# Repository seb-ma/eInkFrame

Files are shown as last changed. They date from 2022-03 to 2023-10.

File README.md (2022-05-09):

# Weather station e-ink frame

This is a project (hardware and software parts) designed to have a full Weather station (and many more features) displayed on a e-ink screen put in a photo frame with tactile buttons.

It is done with a Raspberry Pi, a 7.8" e-ink screen, a capacitive touch sensor, a temperature/humidity/pressure/gas sensor and needs a internet connection.

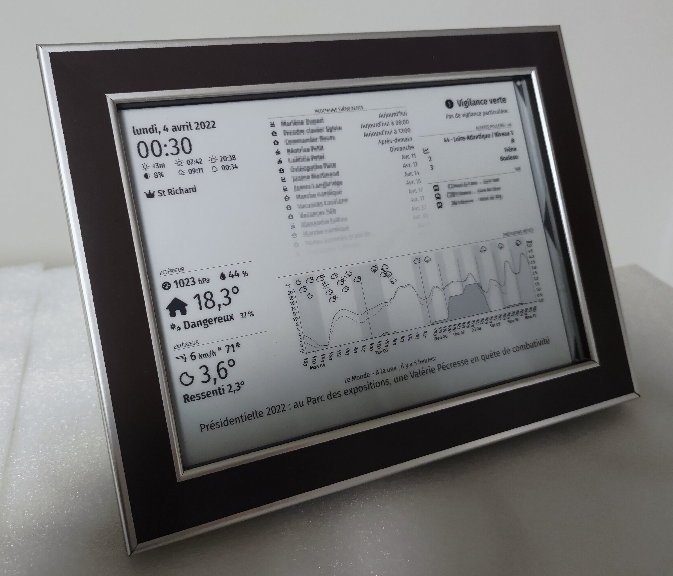
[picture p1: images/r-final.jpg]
final


## Status

This project is fully functional.

Some improvements can be done (see [MagicMirror² Installation](software.md#Disclaimer)) and more features may be added in the future (see below).

## Hardware

Complete guide is in [hardware part](hardware.md).

It includes:
- Information on schematic
- Bill Of Material

## Software

Complete guide is in [software part](software.md).

It includes:
- Installation and configuration of OS on Raspberry
- Installation and configuration of [MagicMirror²](https://magicmirror.builders/) and all the modules

## Features

At this stage, all the ticked features are available (the other features may never be done).
It can also be customized by adding new modules (see [MagicMirror² Installation](software.md#MagicMirror²)).

### Basic

- [X] Current day and time
- [X] sunrise/sunset
- [X] moonrise/moonset
- [X] Gain/loss of sun minutes since yesterday
- [X] Moon phase
- [X] Saint of the day

### Weather/outdoor

- [X] Indoor sensors:
  - [X] temperature
  - [X] humidity
  - [X] pressure
  - [X] air quality
- [X] Current weather with:
  - [X] temperature
  - [X] feel-like temperature
  - [X] humidity
  - [X] pressure
  - [X] wind
  - [X] UV index
  - [X] rain probability
  - [X] air quality
- [X] Graph of weather forecast for next days with:
  - [X] temperature
  - [X] feel-like temperature
  - [X] min/max temperature
  - [X] rain and snow
  - [X] weather icon
  - [X] humidity
  - [X] pressure
  - [X] wind
  - [X] UV index
  - [X] rain probability
  - [X] air quality
  - [ ] same curves for previous days
- [X] Alerts on the risk of rain, wind, ice...
- [X] Alerts on current active allergens
- [ ] Maps of winds, rain, lightning
- [ ] Historic graph of indoor sensor measures

### Calendar and tasks

- [X] Upcoming events in family calendar
- [X] Upcoming birthdays
- [X] Tasks (from Trello)

### Travels

- [X] Next upcoming used bus lines
  - [X] with alerts on this lines
- [X] Travel time to work
- [ ] Map of traffic
- [ ] Traffic for the next event in calendar

### Entertainment

- [X] Headlines of news
- [X] Current Spotify music (watch multiple accounts)
  - [X] with buttons for Spotify control (volume, next/previous, start/stop)
- [ ] Game of life

### Display

- [X] Different pages that can be accessed with buttons

### Advanced features (not yet planned)

- [ ] [Home Assistant](https://www.home-assistant.io/) interaction
- [ ] Communication with home sensors (indoor and outdoor)

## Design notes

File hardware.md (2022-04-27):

# Hardware part

This project was done with KiCad. Schematic and PCB are provided in this format.

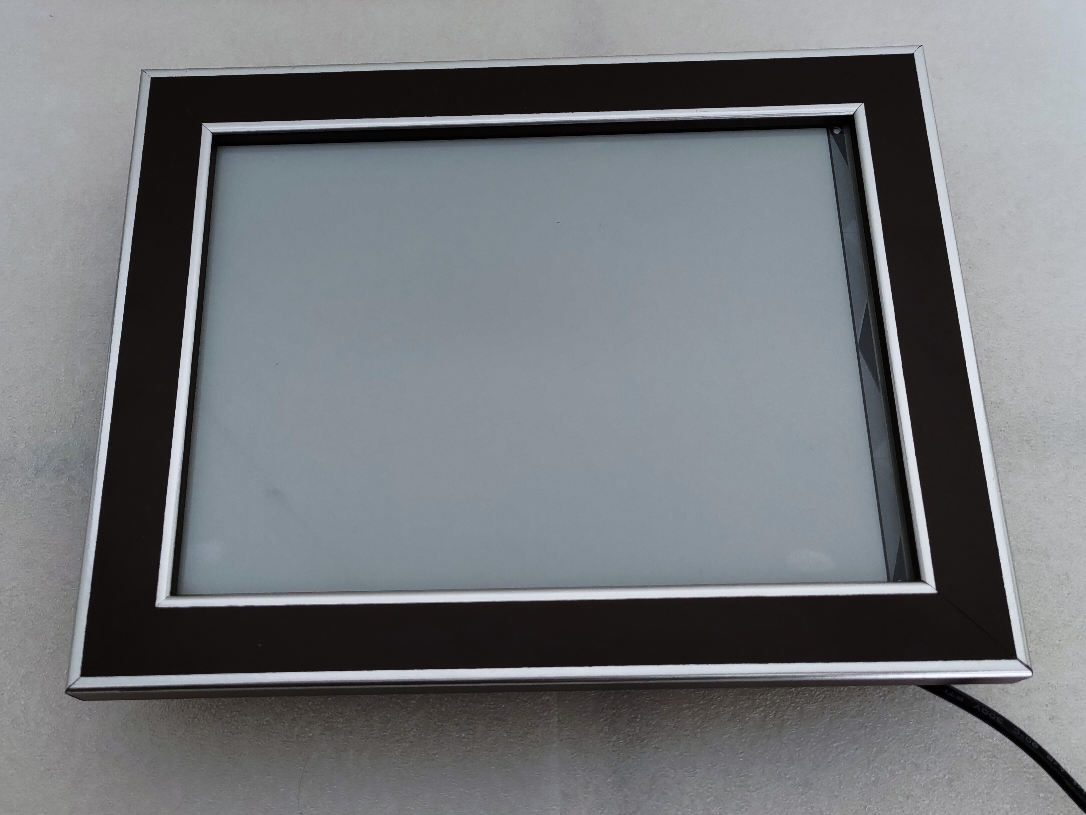
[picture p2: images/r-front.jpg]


- Schematic has a complete overview of all components needed (including sockets, holes and mounting stuff)
    - Each component is socketed
    - A schematic and footprint is provided for SMT socket, (but also component - not used in this project) and simple edge component
    - BOM references are included for Mouser provider
- PCB is done with SMT components to avoid potential shortcuts through accessible pins on background plate
    - Raspberry pi zero footprint is used
    - There is also a classical Raspberry pi footprint available in project (that can fit on PCB if desired)

The KiCad project is located in [pcb](pcb/) folder.

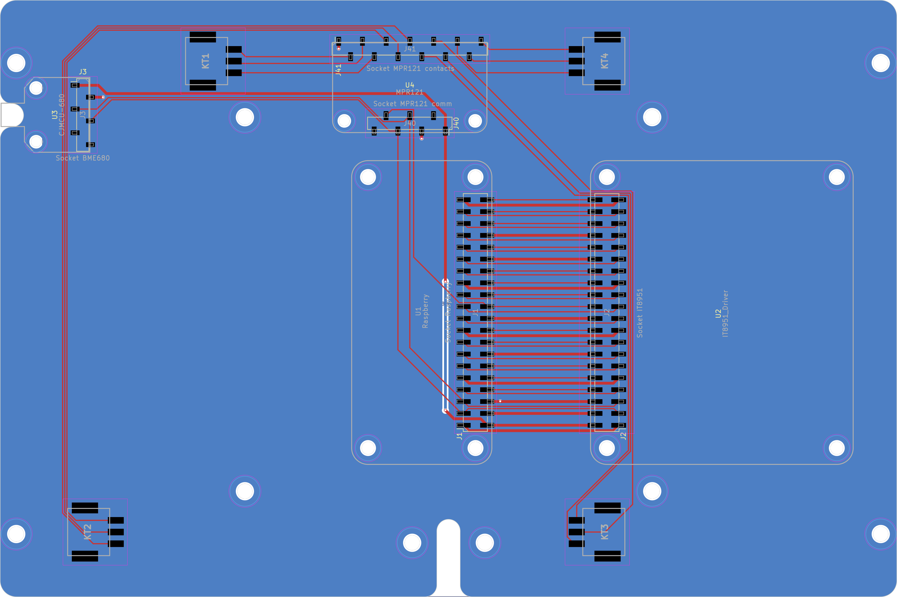
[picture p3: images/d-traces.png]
traces


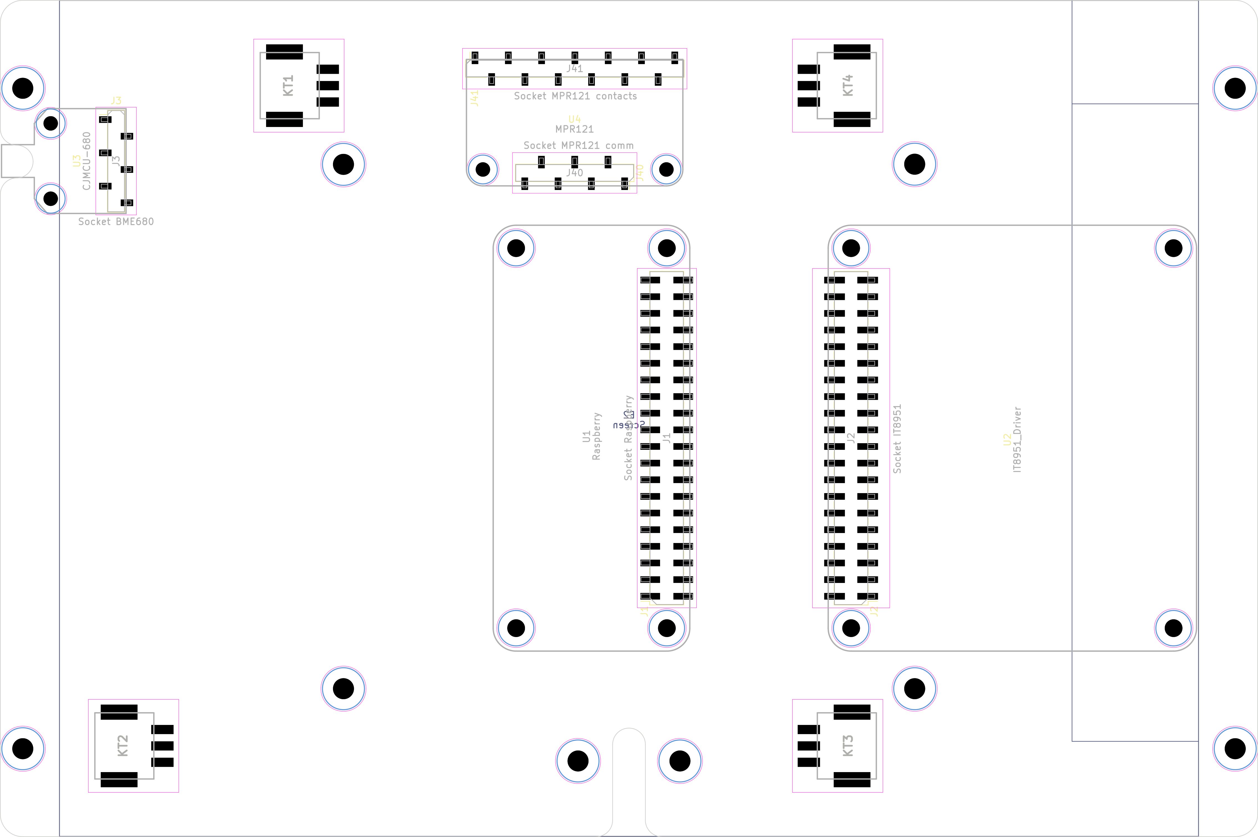
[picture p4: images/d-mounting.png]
mounting


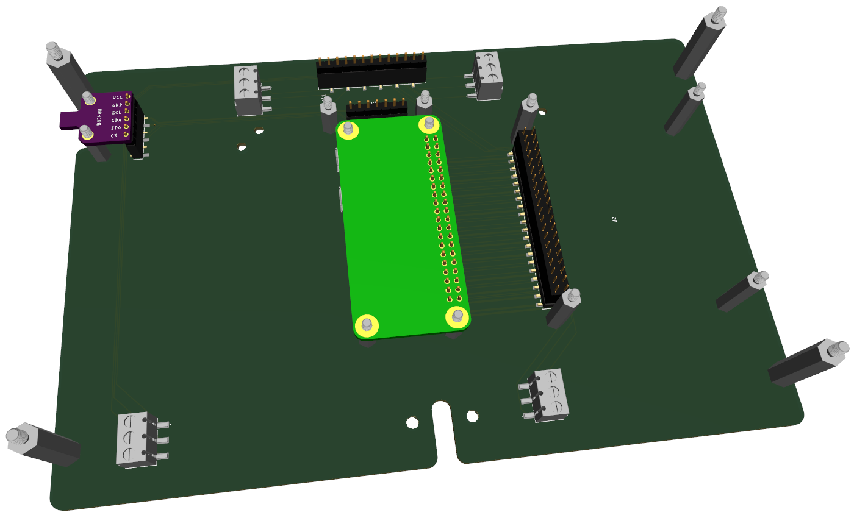
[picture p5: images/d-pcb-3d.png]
pcb-3d


## BOM

Approximate price: 430€ (in 2022)

- e-ink screen: 175€
- Raspberry Pi Zero 2 W + sdcard, power…: 90€
- Temperature/Humidity/Pressure/IAQ Sensor: 20€
- Capacitive touch sensor: 15€
- PCB printing (+shipping): 30€
- Frame: 25€
- Screws, standoffs, nuts, sockets…: 75€

## Detailed BOM

| Description | Mouser ref. | Quantity | Comments |
| --- | --- | --- | --- |
| **UC** |
| Raspberry Pi Zero 2 W |  | 1 | Raspberry pi Zero 2 W on Raspberry website<br>Raspberry 4 should work too (enough space on board) |
| Socket Raspberry | 200-SSM120FDV | 1 | 2x20-pins female socket |
| Standoffs M2.5 | 761-M2105-2545-AL | 4 | Standoffs for Raspberry (pairing with nuts and screws) |
| **Temperature/Humidity/Pressure/IAQ Sensor** |
| CJMCU-680 |  | 1 | Temperature/humidity/pressure/IAQ sensor |
| Socket BME680 | 200-SSM106SSV | 1 | 6-pins female socket |
| **Screen** |
| Waveshare e-ink 7.8” display |  | 1 | 7.8inch e-paper on Waveshare website |
| Socket IT8951 | 649-95278-101-40LF | 1 | 2x20-pins male socket |
| IT8951 ribbon | 710-687640100002 | 1 | The one provided by Waveshare is too long |
| Standoffs M2.5 | 761-M2113-2545-AL | 4 | Standoffs for IT8951 driver (pairing with nuts and screws) |
| **Capacitive keys** |
| Adafruit MPR121 |  | 1 | Capacitive keys<br>Warn: 2 revisions exist with different pins |
| Socket MPR121 contacts | 200-SSM113SSV | 1 | 7-pins female socket |
| Socket MPR121 comm | 200-SSM107LSV | 1 | 13-pins female socket |
| Screw Terminal 01x03 | 651-1814647 | 4 | May be optional by directly ironing wires on pads |
| Wire 24AWG | 650-100G0111-0.25-0 | 4 | Probably less is needed (wires needed from screw terminals to frame picture turn buttons) |
| Terminal | 571-151439 | 12 (or # of needed keys) | To fix wires on frame picture turn buttons |
| Frame picture turn button |  | 12 (or # of needed keys) | As large as possible: used as capacitive keys<br>May be another system like rivets through frame |
| **Frame** |
| Photo frame |  | 1 | Inner dim. 127.6 * 173.8<br>(= screen size) |
| Insert M3 | 153-PFLA-M3-2 | 4 | To fix PCB in frame |
| Standoff M3 | 761-M2115-3005-SS | 4 | Length may differ according to frame height. A secure length is 23mm (pairing with inserts and screws) |
| Screw M3 | 534-9191-3 | 4 | To fix PCB in frame |
| Standoff M3 | 5164-SH1000-F | 2 | To support frame with correct slope (length/position may differ according to frame border size) |
| Nut M3| 144-04M030050HN | 2| To fix standoffs |
| Cable tie | 644-BC1M-S4-M0 | 1 | To maintain USB cable |
| **Misc** |
| Nut M2.5 | 144-04M025045HN | 8 | For Raspberry and IT8951 board |
| Screw M2.5 | 534-29300 | 8 | For Raspberry and IT8951 boards |
| Nut M2 | M80-2430000B | 4 | For CJMU-680 and Adafruit MPR121 boards |
| Screw M2 | 48SM006 | 4 | For CJMU-680 and Adafruit MPR121 boards |
| Standoff M2 | 710-971100244 | 4 | Standoffs for CJMCU-680 and Adafruit MPR121 (pairing with nuts and screws) |

## Photo frame

The frame have some constraints to fit with the PCB:

- back border must have width ≥ 10mm (insert has ~4mm diameter)
- border must have depth ≥ 12mm (insert has ~7mm length)

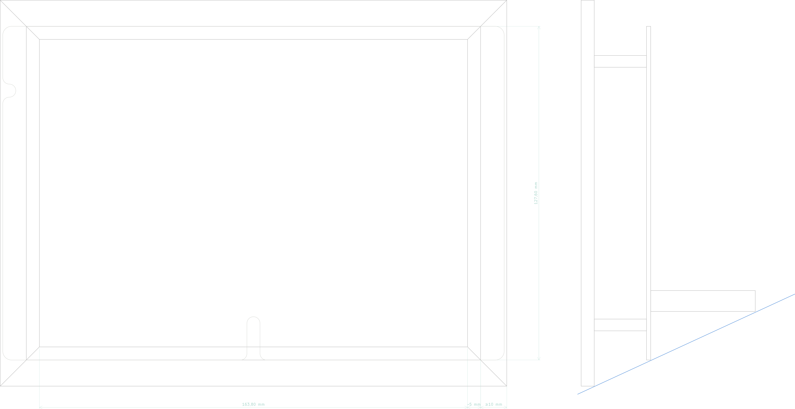
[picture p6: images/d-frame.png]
frame


Nota: right side of the e-ink screen has a bigger margin than the three others sides (~ +5mm).
Ideally a hand-made frame may be created with a non symmetrical back border in order to hide this margin. 

### Standing

- 2 near mounting holes in middle left are made to have a tie that maintain the frame.
- 1 of this mounting hole + a mounting hole on the middle right are made to receive hooks.

## Test Waveshare e-Ink

To check that screen works, compile the following projects:

```sh
# Last version can be found at http://www.airspayce.com/mikem/bcm2835/
cd
wget http://www.airspayce.com/mikem/bcm2835/bcm2835-1.71.tar.gz
tar zxvf bcm2835-1.71.tar.gz
cd bcm2835-1.71/
./configure
make
sudo make check
sudo make install

cd
#git clone https://github.com/waveshare/IT8951-ePaper.git
# Correction of pointers for 64bits
git clone https://github.com/nodfur/IT8951-ePaper.git

cd IT8951-ePaper/Raspberry/
sudo make clean
sudo make -j4
```

Then run:

```sh
# Change value according to value specified on screen (each screen has a different value)
sudo ./epd -1.48 0
```

## Check i²c addresses

i²c communication can be checked with command:

```sh
i2cdetect -y 1
```

## Test BME680 sensor

To check that BME680 sensor works:

```sh
cd
git clone https://github.com/ftmazzone/bme680
cd bme680/
npm install
```

Then run:

```sh
# Test reading values
npm run testSensor
```

## Test MPR121

```sh
cd
git clone https://github.com/adafruit/node_mpr121
cd node_mpr121/
npm install
```

Then run and touch each key:

```sh
node example.js
```

## Assembly result

Here are some pictures from first realisation:

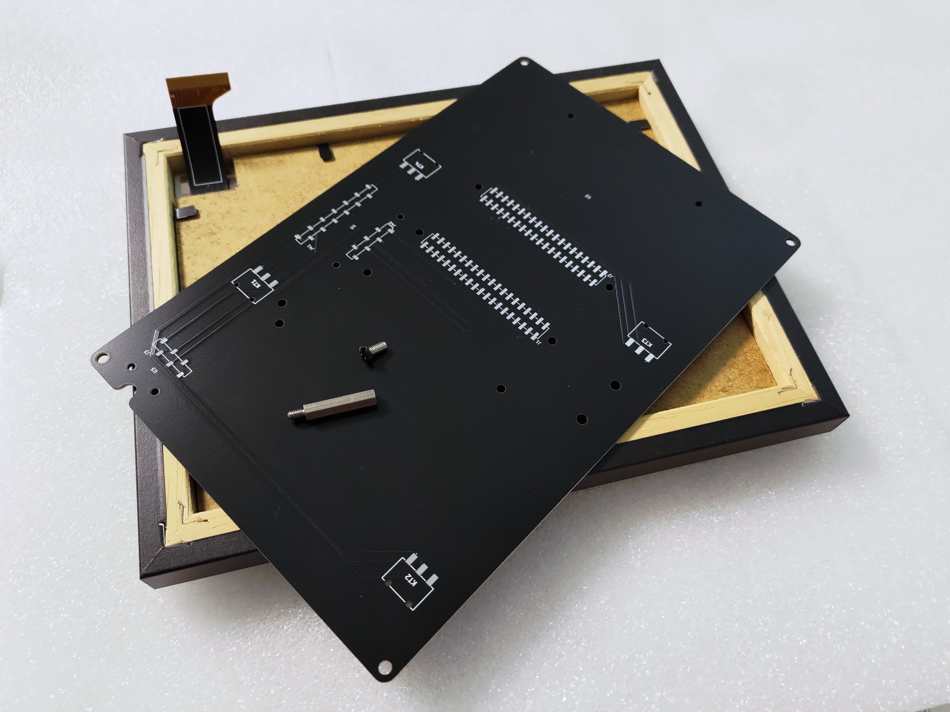
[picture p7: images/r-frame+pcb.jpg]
frame


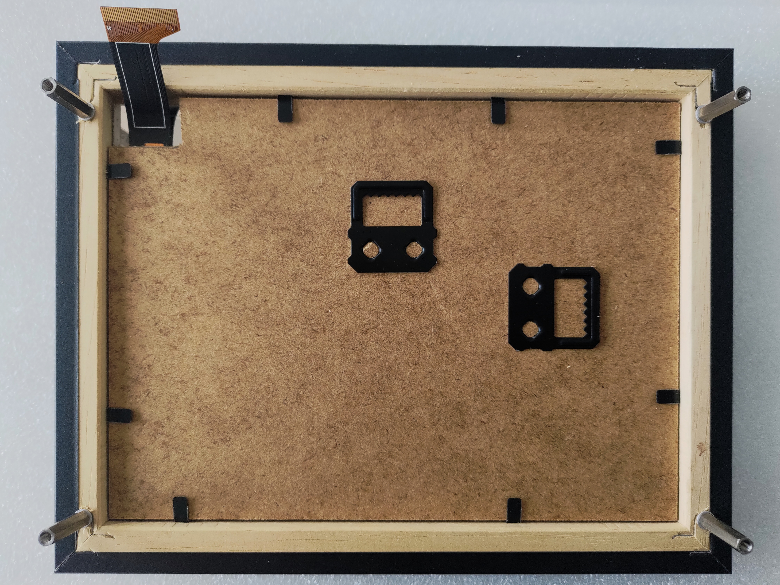
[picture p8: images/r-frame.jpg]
frame


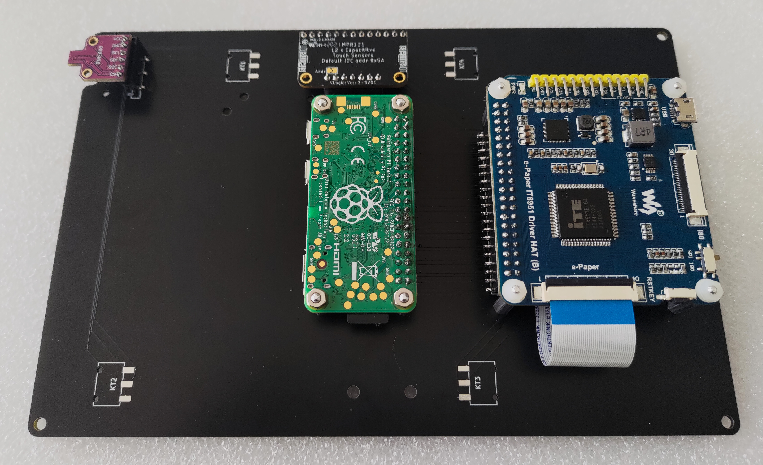
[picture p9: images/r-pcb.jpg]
pcb


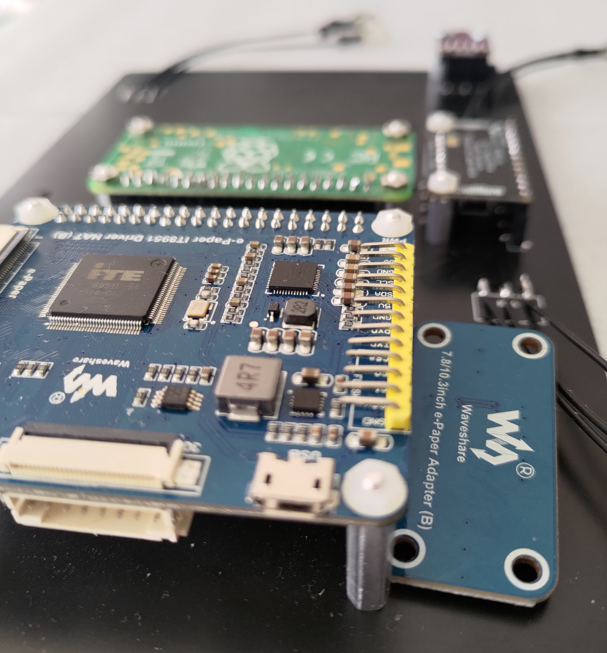
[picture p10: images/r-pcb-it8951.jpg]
pcb detail on it8951


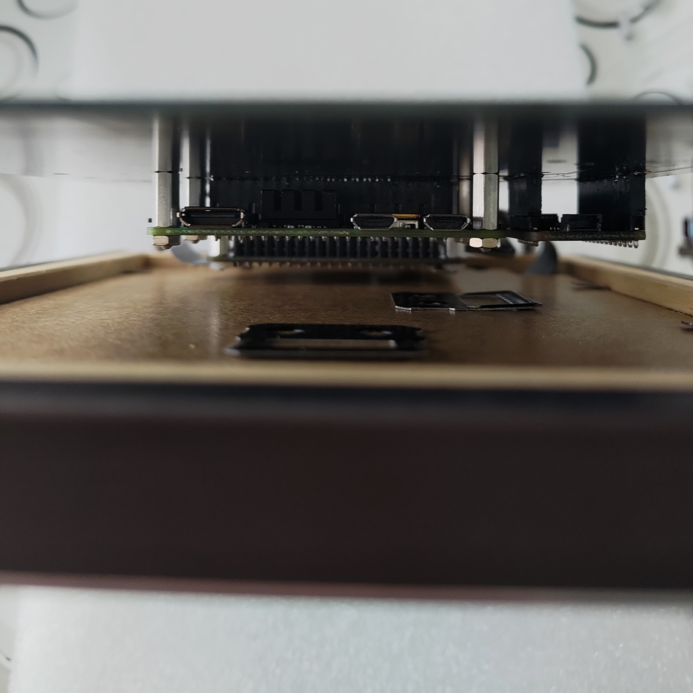
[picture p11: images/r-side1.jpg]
side 1


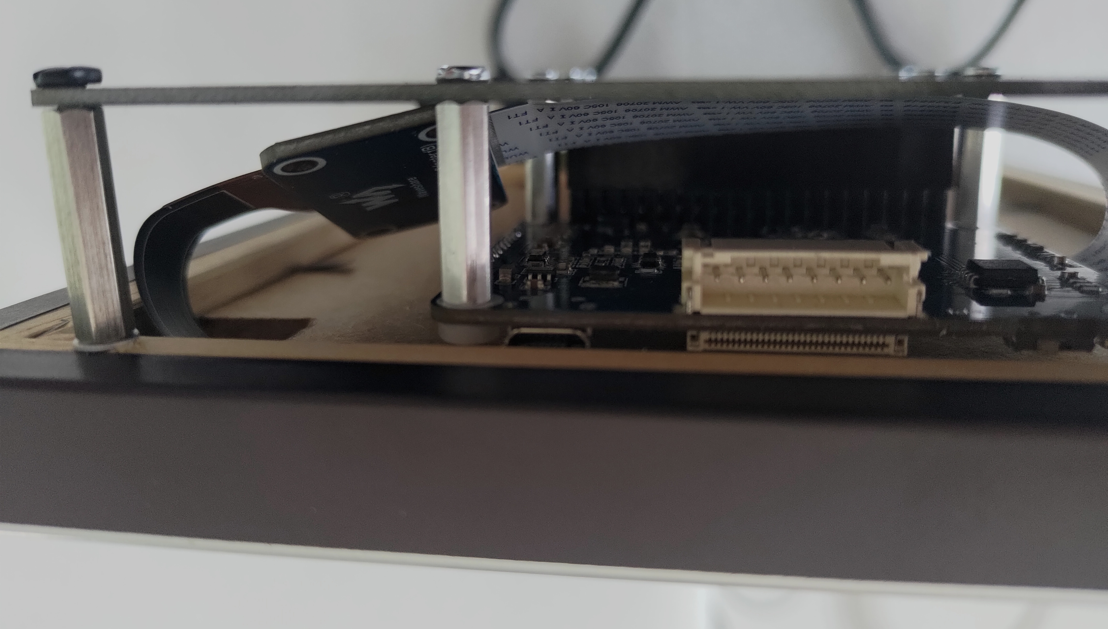
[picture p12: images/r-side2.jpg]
side 2


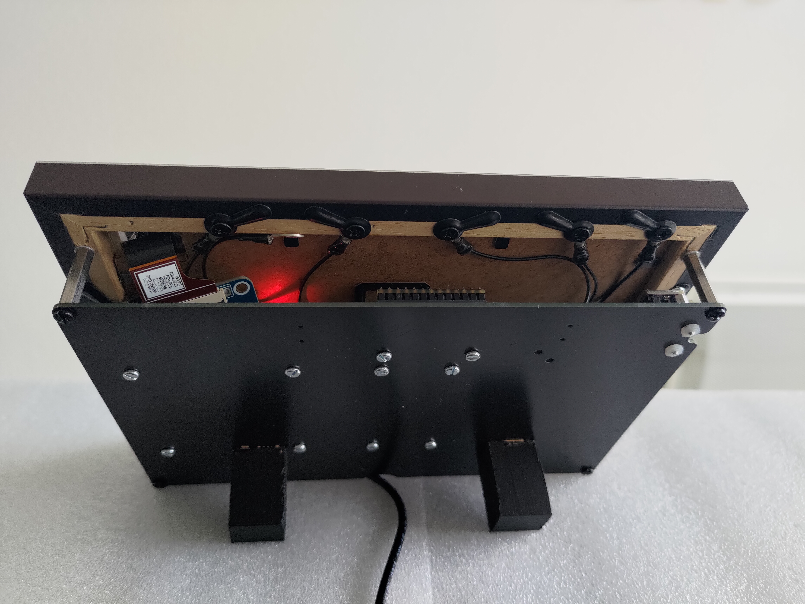
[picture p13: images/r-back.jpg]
frame (back)


frame (front)

## Useful references during development

### KiCad

- KiCad EDA: [https://www.kicad.org/](https://www.kicad.org/)

### Raspberry Pi Zero 2 W

- Raspberry pinout: [https://pinout.xyz/#](https://pinout.xyz/#)
- 3D model by [Hasanain Shuja](https://grabcad.com/hasanain.shuja-1)

### Waveshare e-ink 7.8”

- Waveshare e-ink and driver hat: [https://www.waveshare.com/product/displays/e-paper/epaper-1/7.8inch-e-paper-hat.htm](https://www.waveshare.com/product/displays/e-paper/epaper-1/7.8inch-e-paper-hat.htm)
- Waveshare 7.8inch e-Paper HAT(including links to schematics, spec and datasheets): [https://www.waveshare.com/wiki/7.8inch_e-Paper_HAT](https://www.waveshare.com/wiki/7.8inch_e-Paper_HAT)

### Adafruit MPR121 module

- MPR121 Capacitive Touch Sensor on Raspberry Pi: [https://learn.adafruit.com/adafruit-mpr121-12-key-capacitive-touch-sensor-breakout-tutorial/overview](https://learn.adafruit.com/adafruit-mpr121-12-key-capacitive-touch-sensor-breakout-tutorial/overview)

### CJMCU-680

- 3D model by [Hasanain Shuja](https://grabcad.com/hasanain.shuja-1)

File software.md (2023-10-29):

# Software part

This project works thanks to [MagicMirror²](https://magicmirror.builders/) *("The open source modular smart mirror platform”)* running on [Raspberry Pi OS](https://www.raspberrypi.com/software/).

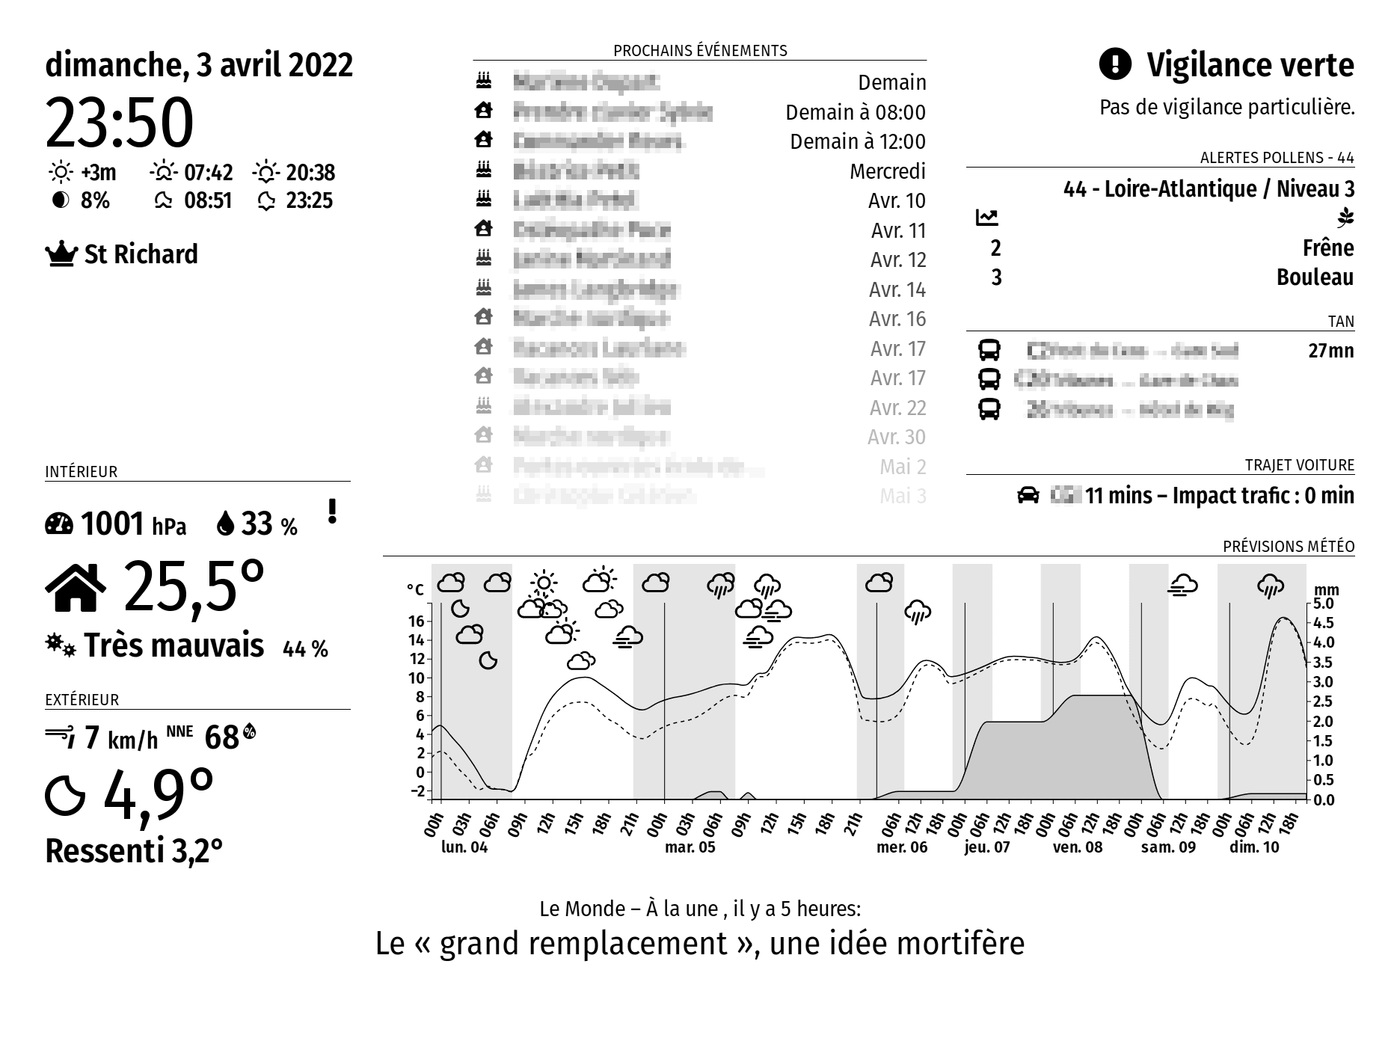
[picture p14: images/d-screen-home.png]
homescreen


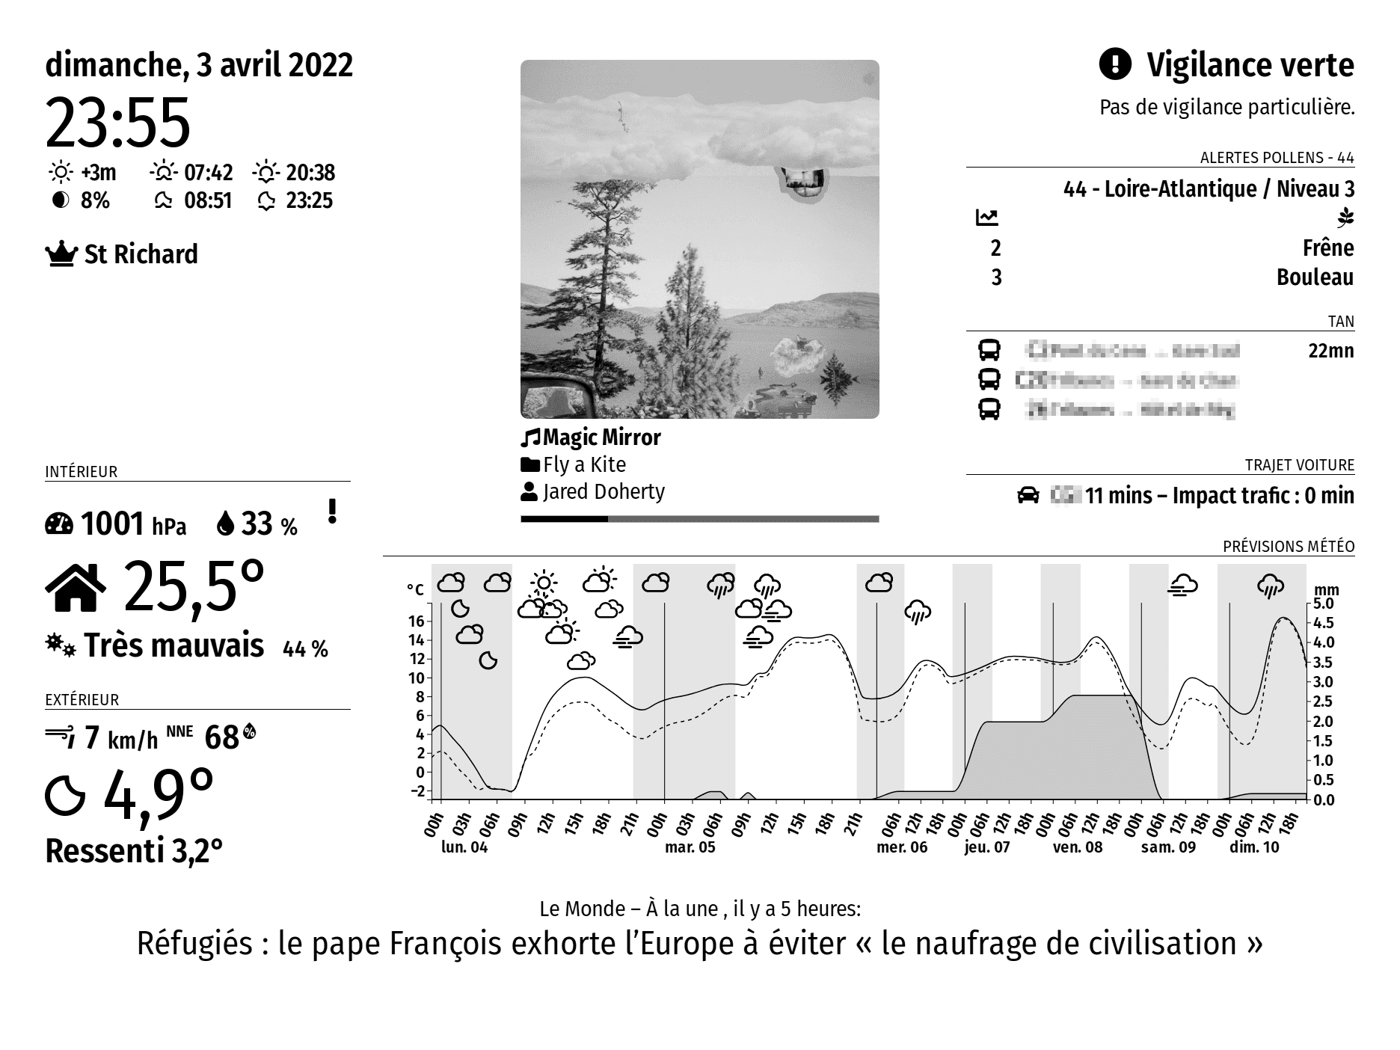
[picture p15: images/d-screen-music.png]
screen music


This document is a guide (step-by-step) to install and configure all software, dependencies and modules from scratch.

## Disclaimer

This guide works but only with the `root` user.

This is due to a problem accessing `/dev/mem` (witch is needed for e-ink).
It currently can't be accessed thru npm call at this stage, neither as `sudo npm` nor with sticky bit or `cap_sys_rawio` capability set.

It works only with user `root` (`sudo su`).

Thus, all parts about `serverusr` must be replaced by `root`.

## Raspberry Pi OS

This section deals with the installation and configuration of the operating system.

### Preparing the SD card

Create the SD card with Raspberry Pi Imager: [Raspberry Pi OS - Raspberry Pi](https://www.raspberrypi.com/software/)
May be installed from Linux distribution of manually.

This project requires a `lite 64-bits` version.

⚠️ Because of a dependency on a module that does not seem to compile on a 32-bit version (`i2c_bus` for `adafruit-mpr121`), it is necessary to use a 64-bit version:
[https://downloads.raspberrypi.org/raspios_full_arm64/images/](https://downloads.raspberrypi.org/raspios_full_arm64/images/)

### SSH activation

Create a file named `ssh` in the `boot` partition of the card (no extension, no content).

### WIFI activation and configuration

Create a file named `wpa_supplicant.conf` in the `boot` partition of the card.
The file should contain the following data (change SSID and password):

```properties
ctrl_interface=DIR=/var/run/wpa_supplicant GROUP=netdev
update_config=1
country=FR

network={
  ssid="SSID"
  psk="password"
  key_mgmt=WPA-PSK
}
```

### Security

<aside>
ℹ️ By default, the user is `pi` and the password is `raspberry`.
</aside>

```sh
# Change the password
passwd
```

### Raspberry configuration

```sh
sudo raspi-config
```

- Change timezone
  - Location Options
  - Change Timezone
- Change keyboard layout
  - Location Options
  - Change Keyboard Layout
- Enable SPI
  - Interfacing options
  - SPI Enable / Disable automatic loading of SPI core module
- Enable i²c
  - Interfacing options
  - I2C Enable / Disable automatic loading of the I2C kernel module

### Creation and privileges of a specific user

To run MagicMirror², a specific user `serverusr` is created.

```sh
# Creation of the user running the MagicMirror service
sudo adduser serverusr
# Add user to the groups allowing access to the i2c and spi
sudo adduser serverusr i2c
sudo adduser serverusr spi
sudo adduser serverusr kmem
```

Add `serverusr` user to sudoers for `shutdown` command.
Edit sudoers file:

```sh
sudo visudo
```

Add line:

```sh
serverusr ALL=NOPASSWD: /sbin/shutdown
```

### GPIO access

Configure GPIO access (from https://github.com/jperkin/node-rpio):

Disable GPIO interrupts:

Edit `/boot/config.txt`:

```sh
sudo nano /boot/config.txt
```

Add following line:

```properties
dtoverlay=gpio-no-irq
```

Enable `/dev/gpiomem` access:

Create `/etc/udev/rules.d/20-gpiomem.rules`:
```sh
sudo nano /etc/udev/rules.d/20-gpiomem.rules
```

Add following line:

```properties
SUBSYSTEM=="bcm2835-gpiomem", KERNEL=="gpiomem", GROUP="gpio", MODE="0660"
```

### Installation of the necessary packages

```sh
# Installation of auto updates
sudo apt install -y unattended-upgrades
# Installation of MagicMirror dependencies
sudo apt install -y npm nodejs
# Installation of tools
sudo apt install -y git make gcc g++
sudo apt install -y ca-certificates curl gnupg
# To compile and install native addons from npm you may also need to install build tools
sudo apt install -y build-essential
# Installation of modules dependencies
sudo apt install -y chromium-browser
```

### Installation of more up-to-date nodejs package

Installation of a required nodejs version using project https://github.com/nodesource/distributions.

```sh
# Download and import the Nodesource GPG key
sudo mkdir -p /etc/apt/keyrings
curl -fsSL https://deb.nodesource.com/gpgkey/nodesource-repo.gpg.key | sudo gpg --dearmor -o /etc/apt/keyrings/nodesource.gpg
# Create deb repository
NODE_MAJOR=20
echo "deb [signed-by=/etc/apt/keyrings/nodesource.gpg] https://deb.nodesource.com/node_$NODE_MAJOR.x nodistro main" | sudo tee /etc/apt/sources.list.d/nodesource.list
# Install nodejs
sudo apt install -y nodejs
```

### Automatic updates

### System update

Configure automatic updates for the distribution:

Run the following commands to create the automatic updates configuration files:

```sh
echo 'APT::Periodic::Enable "1";
APT::Periodic::Update-Package-Lists "1";
APT::Periodic::Unattended-Upgrade "1";
APT::Periodic::AutocleanInterval "7";'
| sudo tee /etc/apt/apt.conf.d/20auto-upgrades

```sh
sudo nano /etc/apt/apt.conf.d/50unattended-upgrades
```

Uncomment / Edit following lines:

```js
Unattended-Upgrade::Origins-Pattern {
        "origin=Debian,codename=${distro_codename}-updates";
//      "origin=Debian,codename=${distro_codename}-proposed-updates";
        "origin=Debian,codename=${distro_codename},label=Debian";
        "origin=Debian,codename=${distro_codename},label=Debian-Security";
        "origin=Debian,codename=${distro_codename}-security,label=Debian-Security";
};

Unattended-Upgrade::Automatic-Reboot True;
Unattended-Upgrade::Automatic-Reboot-Time "03:00";'
```

### Increasing the swap

The Raspberry pi zero 2 W has few RAM.

In order to be able to compile some modules, it is necessary to have a larger swap than the default (100mb)

```sh
sudo nano /etc/dphys-swapfile

# change the line to "CONF_SWAPSIZE=1024

sudo dpkg-reconfigure dphys-swapfile
```

### Limiting writes to the SD card

To increase the life of the SD card, it is possible to mount the `tmp` partition and logs directory in RAM (or disable logs).

### Change `/tmp` to `tmpfs`.

Run the command :

```sh
sudo cp -v /usr/share/systemd/tmp.mount /etc/systemd/system/
sudo systemctl enable tmp.mount
```

### Change `/var/log` to `tmpfs`.

Edit the `/etc/fstab` file:

```sh
sudo nano /etc/fstab
```

Add the following lines (if they have no entries) to the `/etc/fstab` file:

```sh
tmpfs /tmp tmpfs defaults,noatime,nosuid,nodev,size=100M 0 0
tmpfs /var/tmp tmpfs defaults,noatime,nosuid,nodev,noexec,size=10M 0 0
tmpfs /var/log tmpfs defaults,noatime,nosuid,nodev,noexec,mode=0755,size=10M 0 0
```

### Limit log files size

To limit size of logs to `1M`, edit the `/etc/systemd/journald.conf` file:

```sh
sudo nano /etc/systemd/journald.conf
```

Replace the following lines:

```sh
#Storage=volatile
#RuntimeMaxUse=
```

by:

```sh
Storage=volatile
RuntimeMaxUse=1M
```

### Set hostname

Change hostname to `einkframe`

```sh
sudo echo "einkframe" > /etc/hostname
```

### Reboot the OS

When configuration is done, run the following command to reboot:

```sh
sudo reboot
```

### Add SSH public key

To configure SSH for login without password, execute from computer:

```sh
ssh-copy-id -i ~/.ssh/<filename.pub> pi@einkframe.local
```

## MagicMirror²

This section deals with the installation and configuration of the application and data display modules.

See [MagicMirror²](https://magicmirror.builders/) for details.

### Installation

See [Installation & Usage | MagicMirror² Documentation](https://docs.magicmirror.builders/getting-started/installation.html#manual-installation) for details.

Run the script [installMM.sh](magicmirror_files/installMM.sh) commands to retrieve and install MagicMirror² and all necessary modules for this project:
Then, apply patch [applyPatches.sh](magicmirror_files/applyPatches.sh) to adapt some modules that need it.

```sh
cd ~
git clone https://github.com/seb-ma/eInkFrame
eInkFrame/magicmirror_files/installMM.sh
```

<aside>
ℹ️ List (not exhaustive) of existing modules: [3rd Party Modules - MichMich/MagicMirror Wiki](https://github.com/MichMich/MagicMirror/wiki/3rd-party-modules#development--core-magicmirror)
</aside>

### Setting up the modules

<aside>
ℹ️ General configuration information: [Configuration Module | MagicMirror² Documentation](https://docs.magicmirror.builders/modules/configuration.html)
</aside>

The configuration is split in 2 parts:

- one for near all of the configuration including modules (variable `config`)
- one specific for all private data (location, api keys, passwords) (variable `configPrivateParts`)

Edit the configuration file in `~/MagicMirror/config/` and fill variable `configPrivateParts` (+ adapt configuration of each module if necessary).

To adapt modules position, see visual representation of module positions in a [thread of MagicMirror² forum: module positions](https://forum.magicmirror.builders/topic/286/regions).

[https://docs.magicmirror.builders/configuration/introduction.html](https://docs.magicmirror.builders/configuration/introduction.html)

```sh
nano ~/MagicMirror/config/config.js
```

And fill needed data.
Some modules need a specific initialization in order to work.
Follow each procedure:

- MMM-FreeBox-Monitor: [https://github.com/tataille/MMM-FreeBox-Monitor#readme](https://github.com/tataille/MMM-FreeBox-Monitor#readme)
- MMM-Spotify: [https://github.com/skuethe/MMM-Spotify#install](https://github.com/skuethe/MMM-Spotify#install)
- MMM-Trello: [https://github.com/Jopyth/MMM-Trello#readme](https://github.com/Jopyth/MMM-Trello#readme)
- MMM-VigilanceMeteoFrance: [https://github.com/grenagit/MMM-VigilanceMeteoFrance#readme](https://github.com/grenagit/MMM-VigilanceMeteoFrance#readme)

### Modify display styles

Custom CSS is copied by install script into `~/MagicMirror/css/custom.css`.

### Manual execution

To run MagicMirror² run the following command in `~/MagicMirror` directory:

```sh
npm run server
```

### Automatic execution

Create a service to automatically start the server:

```sh
sudo nano /etc/systemd/system/magicmirror.service
```

Put the following content in the file:

```properties
[Unit]
Description=MagicMirror²
After=network.target
StartLimitIntervalSec=0

[Service]
Type=simple
Restart=always
RestartSec=1
User=serverusr
WorkingDirectory=/home/serverusr/MagicMirror/
ExecStart=node serveronly

[Install]
WantedBy=multi-user.target
```

Enable and start the service:

```sh
# Starting the service
sudo systemctl start magicmirror.service
systemctl status magicmirror.service
# Enabling the service
sudo systemctl enable magicmirror.service
```

### Upgrade (including modules)

To update MagicMirror² and all installed modules, run the commands in the script [updateMM.sh](magicmirror_files/updateMM.sh)

```sh
updateMM.sh
```

NB: Some modules may need a `npm update` before `npm install` to resolve electron-rebuild/node-abi version detection error.

### Access to the screen from a browser

Within the same network, open http://einkframe.local:8080/ in a browser. 

## Manual update

Run the following commands:

```sh
# Distribution
sudo apt update
sudo apt full-upgrade -y
sudo apt clean
```

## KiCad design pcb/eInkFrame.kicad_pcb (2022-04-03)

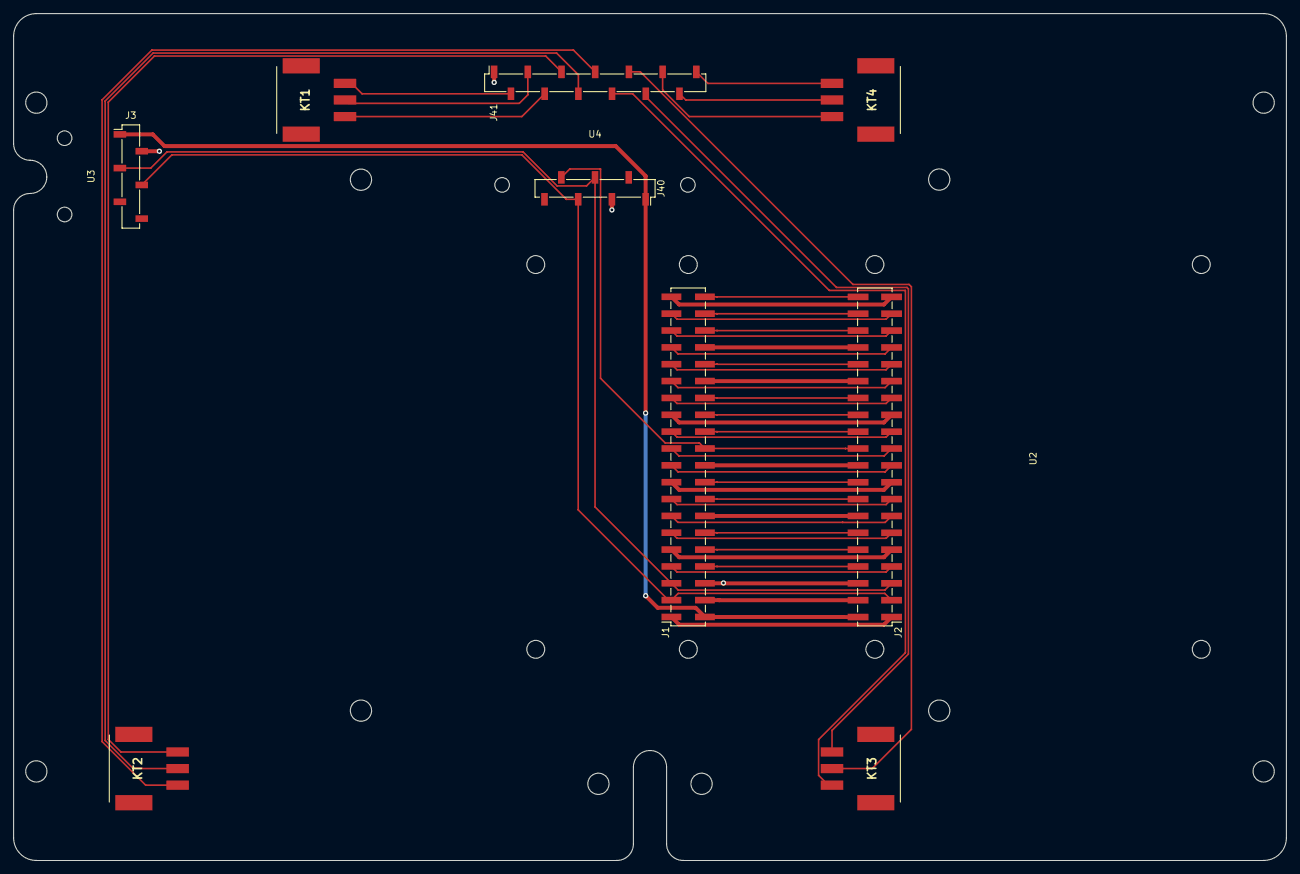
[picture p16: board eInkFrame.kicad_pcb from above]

Board: 2 copper layers, 191.8 x 127.7 mm, 24 parts (1 on the bottom side), 52 nets.

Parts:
E2: Screen; Waveshare eink 7.8
H1, H2, H3, H4, H5, H6: M3; MountingHole_3.2mm_M3
HF1, HF2, HF3, HF4: M3; MountingHole_3.2mm_M3
J1: Socket Raspberry; PinSocket_2x20_P2.54mm_Vertical_SMD
J2: Socket IT8951; PinHeader_2x20_P2.54mm_Vertical_SMD
J3: Socket BME680; PinSocket_1x06_P2.54mm_Vertical_SMD_Pin1Left
J40: Socket MPR121 comm; PinSocket_1x07_P2.54mm_Vertical_SMD_Pin1Right
J41: Socket MPR121 contacts; PinSocket_1x13_P2.54mm_Vertical_SMD_Pin1Right
KT1, KT2, KT3, KT4: Terminal_01x03; Phoenix contact 1814647
U1: Raspberry; Raspberry uHAT (Socket)
U2: IT8951_Driver; IT8951 driver HAT (Socket)
U3: CJMCU-680; CJMCU-680 HAT (Socket)
U4: MPR121; Adafruit MPR121 (Socket)

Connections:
/G1: J1.1 (3v3), J2.1
/G4: J1.4 (5V), J2.4
/G7: J1.7 (gpio_4), J2.7
/G8: J1.8 (gpio_14), J2.8
/G9: J1.9 (Gnd), J2.9
/G10: J1.10 (gpio_15), J2.10
/G11: J1.11 (gpio_17), J2.11
/G12: J1.12 (gpio_18), J2.12
/G13: J1.13 (gpio_27), J2.13
/G14: J1.14 (Gnd), J2.14
/G15: J1.15 (gpio_22), J2.15
/G16: J1.16 (gpio_23), J2.16
/G17: J1.17 (3v3), J2.17
/G18: J1.18 (gpio_24), J2.18
/G19: J1.19 (SPI0_MOSI), J2.19
/G20: J1.20 (Gnd), J2.20
/G21: J1.21 (SPI0_MISO), J2.21
/G23: J1.23 (SPI0_SCLK), J2.23
/G24: J1.24 (SPI0_CE0), J2.24
/G25: J1.25 (Gnd), J2.25
/G26: J1.26 (SPI0_CE1), J2.26
/G27: J1.27 (gpio_0), J2.27
/G28: J1.28 (gpio_1), J2.28
/G29: J1.29 (gpio_5), J2.29
/G30: J1.30 (Gnd), J2.30
/G31: J1.31 (gpio_6), J2.31
/G32: J1.32 (gpio_12), J2.32
/G33: J1.33 (gpio_13), J2.33
/G34: J1.34 (Gnd), J2.34
/G35: J1.35 (gpio_19), J2.35
/G36: J1.36 (gpio_16), J2.36
/G37: J1.37 (gpio_26), J2.37
/G38: J1.38 (gpio_20), J2.38
/G39: J1.39 (Gnd), J2.39
/G40: J1.40 (gpio_21), J2.40
GND: J1.6 (Gnd), J2.6, J3.2, J40.3, J41.1
MPR121_INT: J1.22 (gpio_25), J2.22, J40.6
unnamed: J41.2, KT1.1
unnamed: J41.3, KT1.2
unnamed: J41.4, KT1.3
unnamed: J41.5, KT2.1
unnamed: J41.6, KT2.2
unnamed: J41.7, KT2.3
unnamed: J41.8, KT3.1
unnamed: J41.9, KT3.2
unnamed: J41.10, KT3.3
unnamed: J41.11, KT4.1
unnamed: J41.12, KT4.2
unnamed: J41.13, KT4.3
SCL: J1.5 (SCL), J2.5, J3.3, J40.4
SDA: J1.3 (SDA), J2.3, J3.4, J40.5
VIN: J1.2 (5V), J2.2, J3.1, J40.1

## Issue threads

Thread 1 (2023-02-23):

Guide

sdmydbr9, 2023-02-23:
Hi, wonderful project, after seeing this project being beautifully made, I bought myself an eink display and I'm attempting to build one, unfortunately I'm having a hard time following along. I have installed everything as per instructions in the readme, how do I run it now? If you could elaborate it step by step, it would be really helpful

seb-ma, 2023-02-23:
Hello,
If you want help, you'll have to be more precise on your problem.
I already wrote a guide (one for hardware and one for software).
And I thought the software part (https://github.com/seb-ma/eInkFrame/blob/master/software.md) was quite explicit for each step from scratch.

What step causes you trouble?

sdmydbr9, 2023-02-23:
Okay so I have installed and successfully ran the server in the background. I also have the display connected and configured. How do I proceed from here? Pardon me if I sound dumb but this is not really my area and this is my first time using the e ink display.
I already have the sever running in the background.
Now how do I get it to display it on the e ink? Is there a particular script for this or do I run npm start in the einkframe folder?

seb-ma, 2023-02-23:
Have you already tested your eink to be sure it works?
If no, follow the procedure here: https://github.com/seb-ma/eInkFrame/blob/master/hardware.md#test-waveshare-e-ink

A drawback to the driver is that it needs to be run as root. So, MagicMirror must be run by root user.

Another point to check is the compilation of module MMM-IT8951 that I use in MagicMirror to display on eink (see readme of https://github.com/seb-ma/MMM-IT8951).

And when running magicmirror, check logs to get information on errors/warnings that can help understand the problem.

sdmydbr9, 2023-02-24:
Yes I have run the test script and it runs, and I have compiled the modules. My confusion is if I need to start the part separately for refreshing the display.

1. Install necessary packages and configuration settings for the pi.
2. Installation of MagicMirror and modules.
3. Sever running on localhost8080 serveronly.
4. How do I connect to the server from the display, I can connect with the server using my phone or the laptop. Or is the script automatic like the original magic mirror script that and wouldn't need to do anything and will update on its own?

seb-ma, 2023-02-24:
You made a confusion: in my guide, I added a disclaimer to say that it "works but only **with** the root user."
I spent a lot a hours and try many things but nothing else than running MagicMirror with the root user works.
So, when the guide mentions "serverusr", replace it with "root".
Sorry for the confusion.

Now, about displaying on eink: running MagicMirror is enough and you don't have anything else to run.
Some explanations about the "magic" under the hood:
The module MMM-IT8951 starts a Chrome browser that connects to MagicMirror server and set a script on page to observe DOM modifications (display changes). When page's DOM changes, it triggers the MM module. The module takes a screenshot of the modified area and sends this image to eink screen thanks to the driver "node-it8951".

Before running MagicMirror as a service, you must ensure that it works when you run it "manually". It will give you useful information if something goes wrong.
So, stop the service (if running) then start MagicMirror:
`sudo systemctl start magicmirror.service `
`sudo npm run server`

seb-ma, 2023-03-05:
@sdmydbr9 Have you solved your problem now?

sdmydbr9, 2023-03-05:
Yes. It seems to be an issue with the it8951 board. I switched to using another script, not very interactive but does the work. Maybe I will have to get a new board and then try again. Sorry about all the fuzz🙂

seb-ma, 2023-03-05:
Happy to now. I close the issue.
Let me now if something else cause you trouble.

Have fun with your project.

Closed 2023-03-05.

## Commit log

2022-03-07 All preparations (hardware & software files + guide)
    [eInkFrame.kicad_pcb, eInkFrame.kicad_sch]
2022-03-19 Global doc cleanup, pcb and scripts enhancement, adding images
    [eInkFrame.kicad_pcb, eInkFrame.kicad_sch]
2022-03-28 Change a hard to source component and adapt PCB accordingly + hide some Spotify elements + global formatting
    [eInkFrame.kicad_pcb, eInkFrame.kicad_sch]
2022-04-03 New PCB stand, adding photos, minor updates after final mounting
    [eInkFrame.kicad_pcb, eInkFrame.kicad_sch]
2022-04-08 Set in 4-levels gray most of the modules, define each button function, move VigilanceMeteoFrance to left and limit its width
2022-04-16 Add AQI on current weather
